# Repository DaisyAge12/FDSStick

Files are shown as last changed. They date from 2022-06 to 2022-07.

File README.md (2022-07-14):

# A new mod approaches!
This is a new method of installing an FDS Stick into a Sharp Twin Famicom
Rather than having to cut the plastic card cover or have an ugly wire hanging around, this mod gives you a nice professional looking install!

#### How to Install

1. Start by printing the modded cover and snap cover

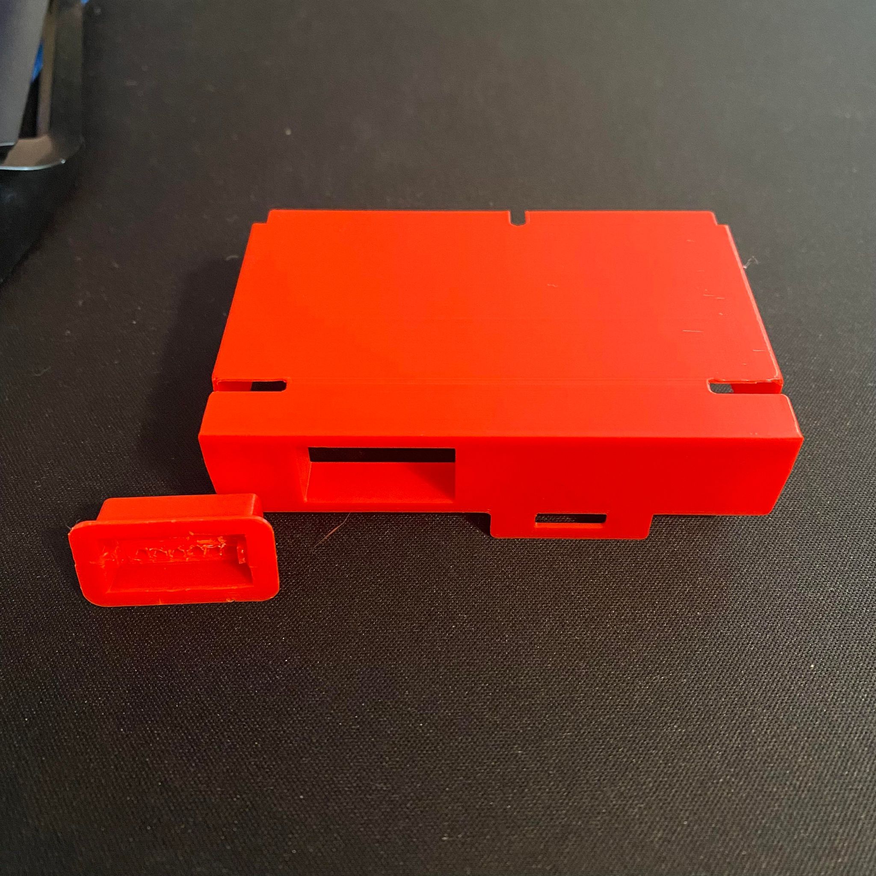
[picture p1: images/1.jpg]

     
2. While that prints (roughly 3 hours) gather materials from the BOM

3. Refer to screenshots for proper installation of the JST connector and header pins

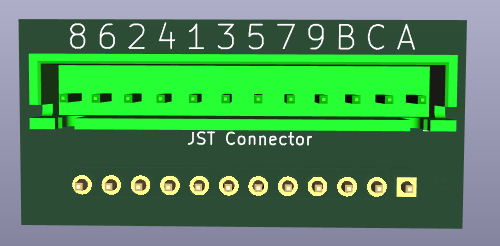
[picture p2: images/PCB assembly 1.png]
 

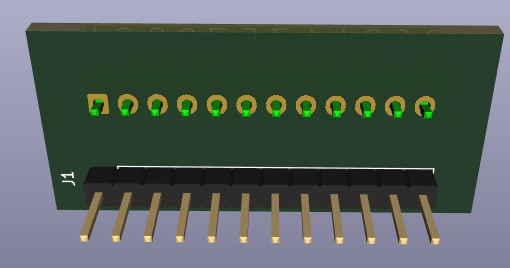
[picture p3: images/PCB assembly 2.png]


4. Use sandpaper, a dremel, or a hot knife to remove the bump from the connector. Note if using a hot knife - pay attention! That's how mine came out so marred.
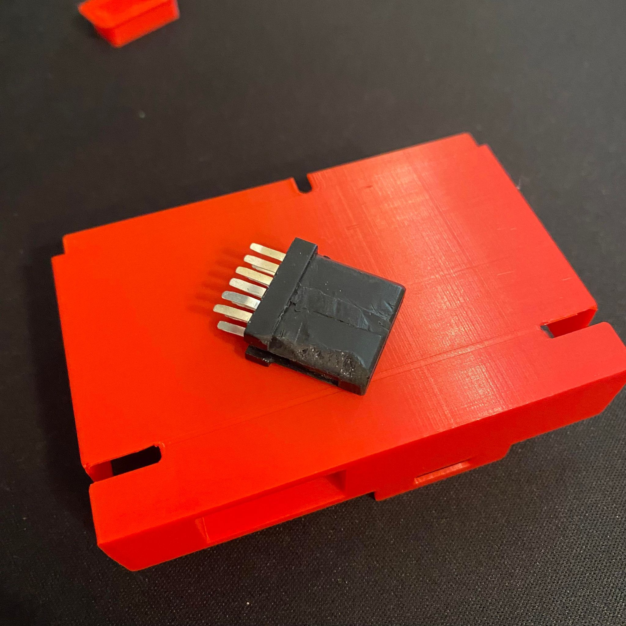
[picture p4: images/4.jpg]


5. Remove locking back for SNES AV and insert the SNES connector into the snap cover (orientation is not important)
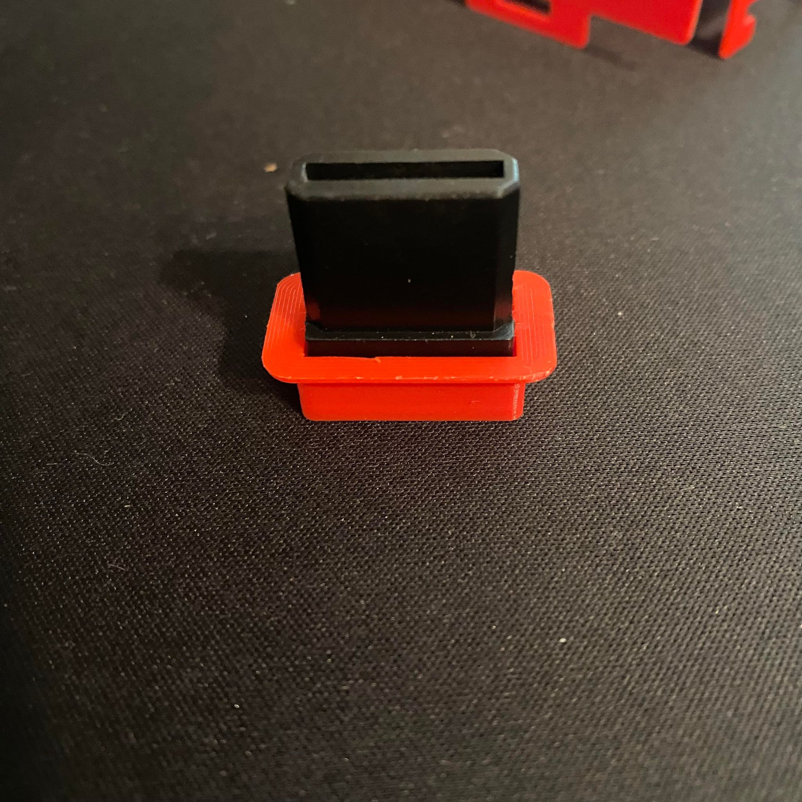
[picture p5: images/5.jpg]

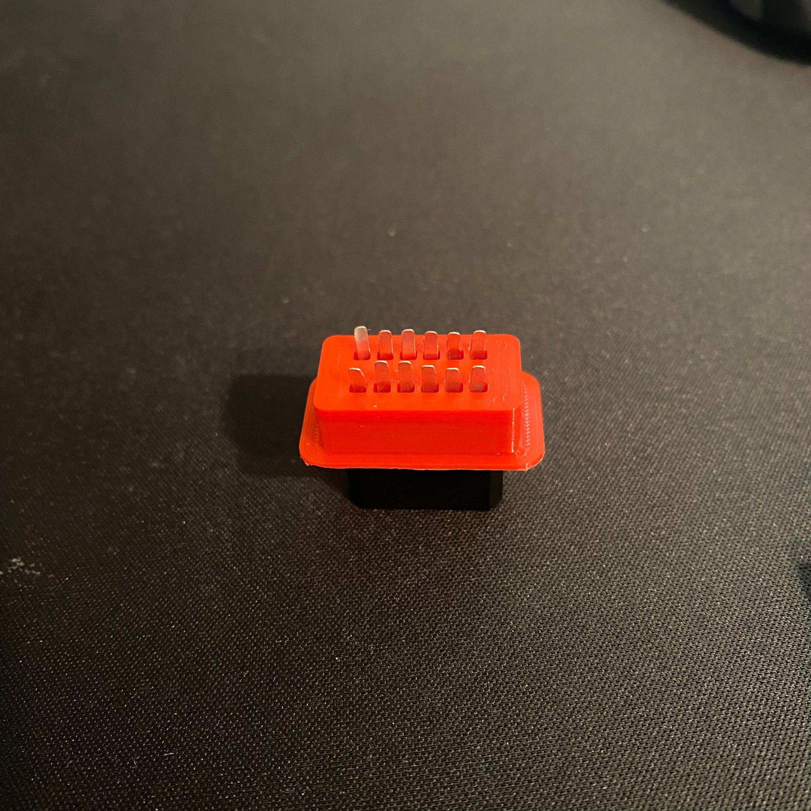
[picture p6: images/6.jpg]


6. Assemble the XHP-12 connector cable as shown in pictures - *do not insert a jumper into pin 12 of the white connector!*
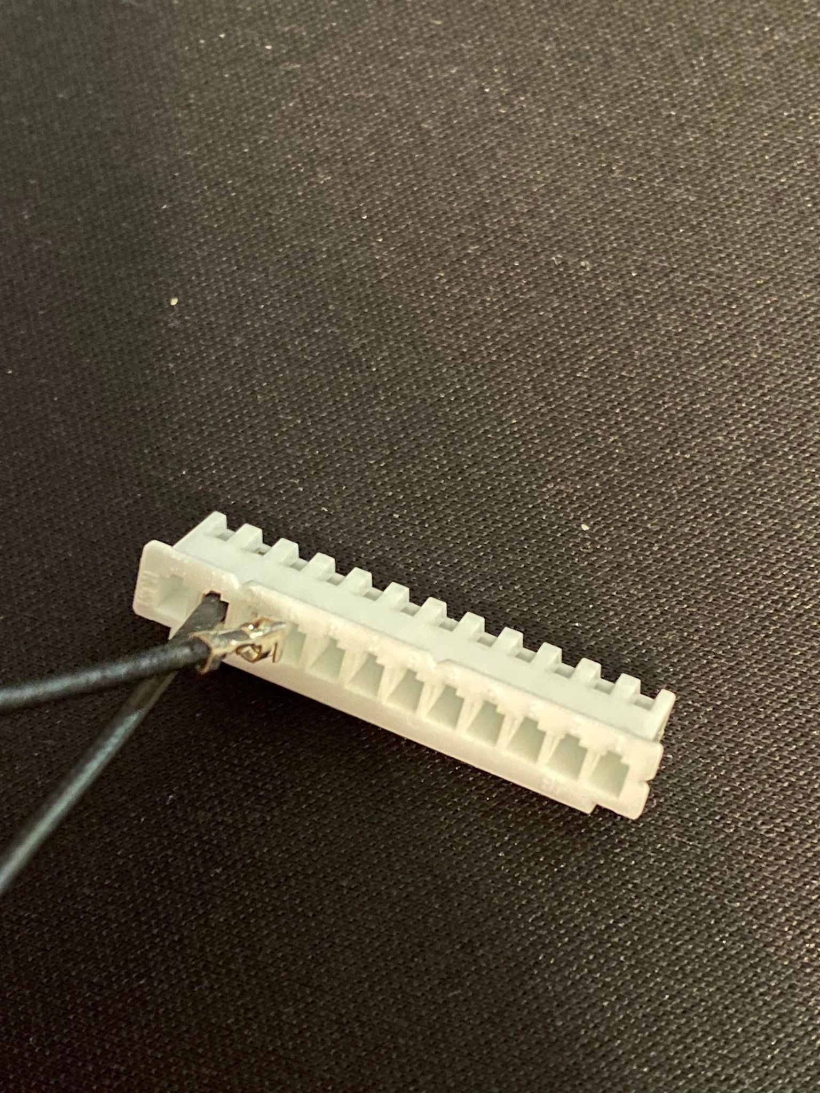
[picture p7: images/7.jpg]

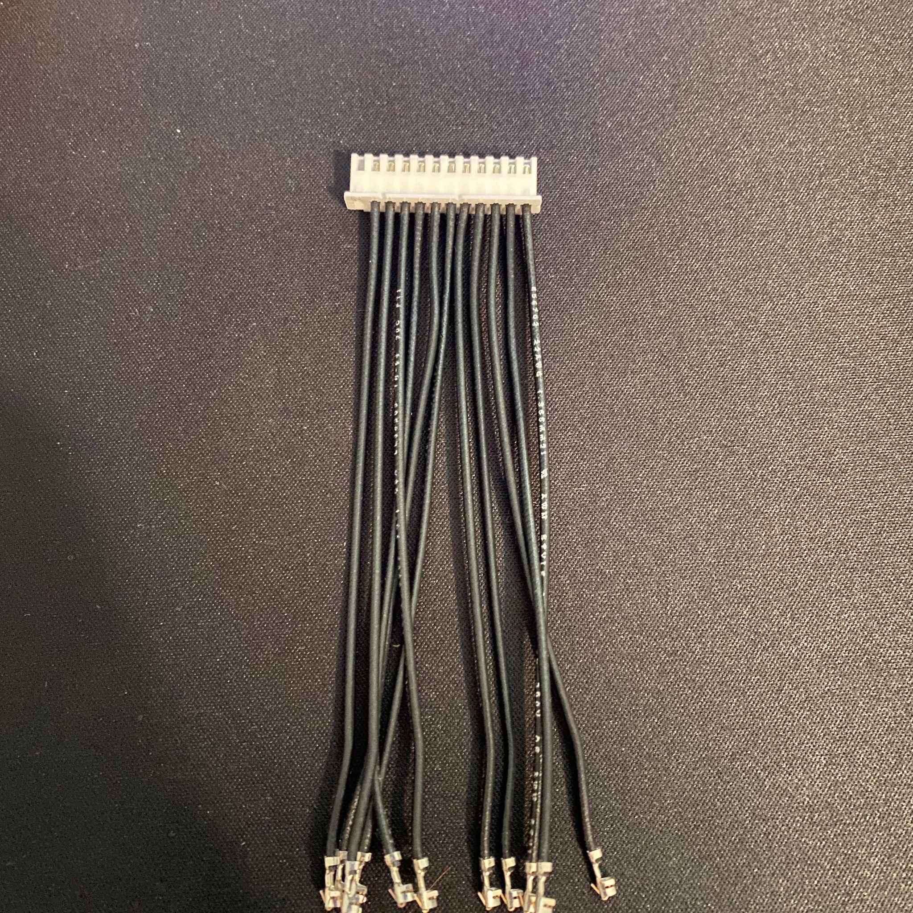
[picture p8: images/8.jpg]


7. Remove the jumper ends and use wire strippers to remove the sheath
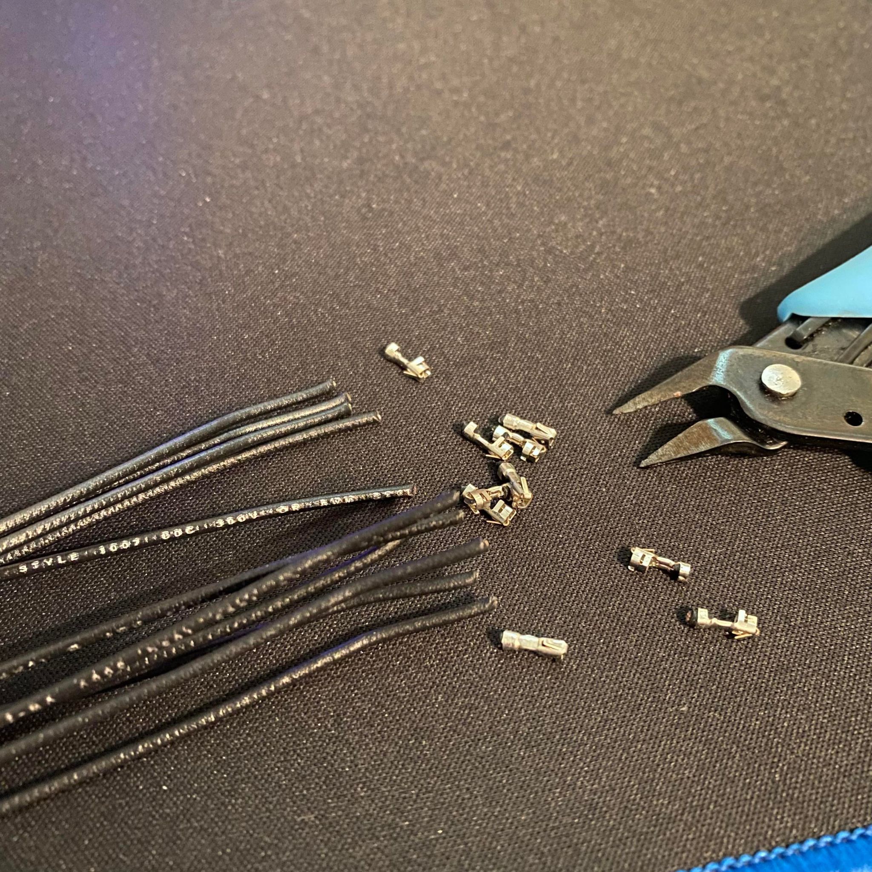
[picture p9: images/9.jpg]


8. Run the wires throught the opening in the modded Twin Famicom cover

9. Install the wires according to this diagram from 3DS Captures site:

**Note**: It is *crucial* that you double check your work as one wrong connection can make your FDS Stick short circuit

**Note**: See how I put my SNES connector upside down? Not only does it hide the ugly parts, it is also my guide so that I know which pins are being soldered to
The goal is to have the FDS Stick facing up so you can easily press the button for flipping disks
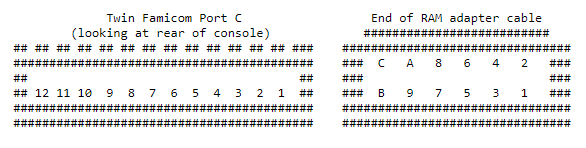
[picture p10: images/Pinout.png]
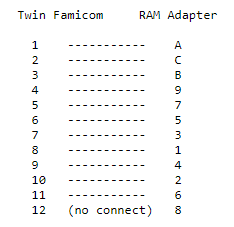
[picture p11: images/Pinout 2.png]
		

10. Insert the ram adapter into the top row of holes in the Twin Famicom - Please see photos 10 & 11
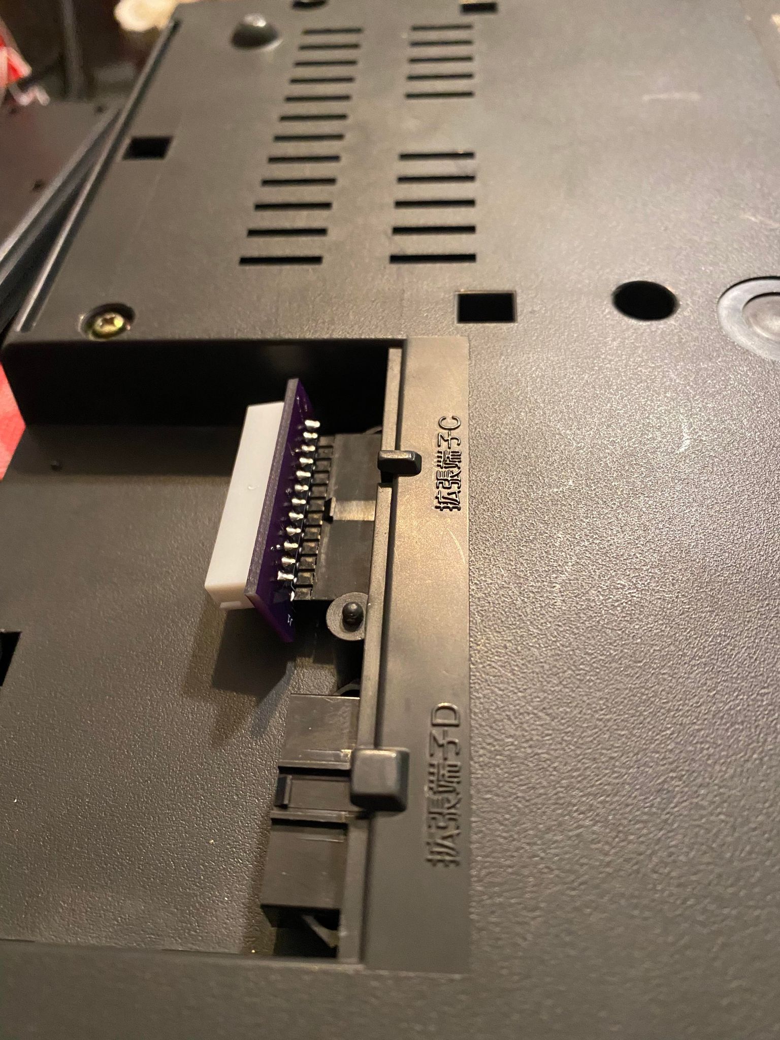
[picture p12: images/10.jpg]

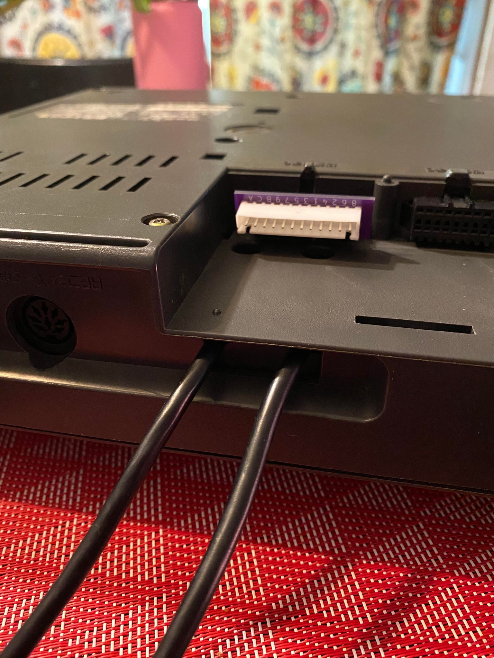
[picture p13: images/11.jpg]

   
11. Carefully snap in the snap cover if you haven't already. If the snap cover isn't tight enough, a small dab of superglue will do the trick.
**Remember** orientation is important! You dont want to fry your FDS Stick
    
12. Connect the white connector
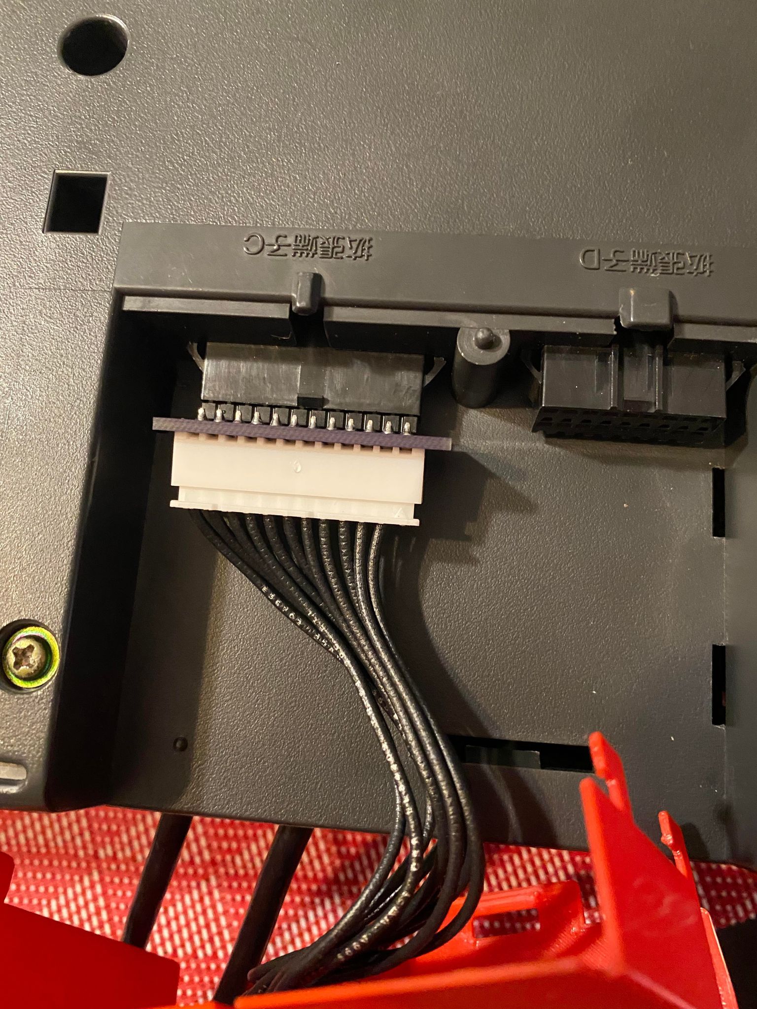
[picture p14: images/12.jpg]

    
13. Carefully install the modded Famicom cover
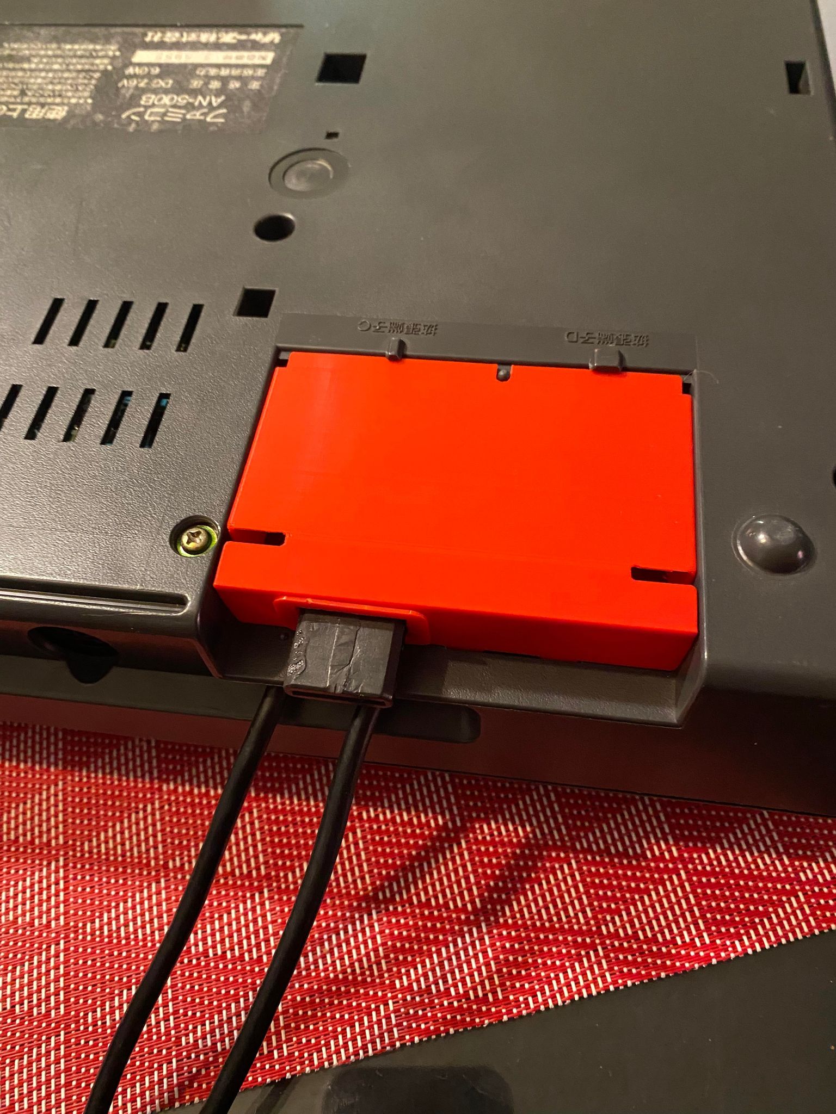
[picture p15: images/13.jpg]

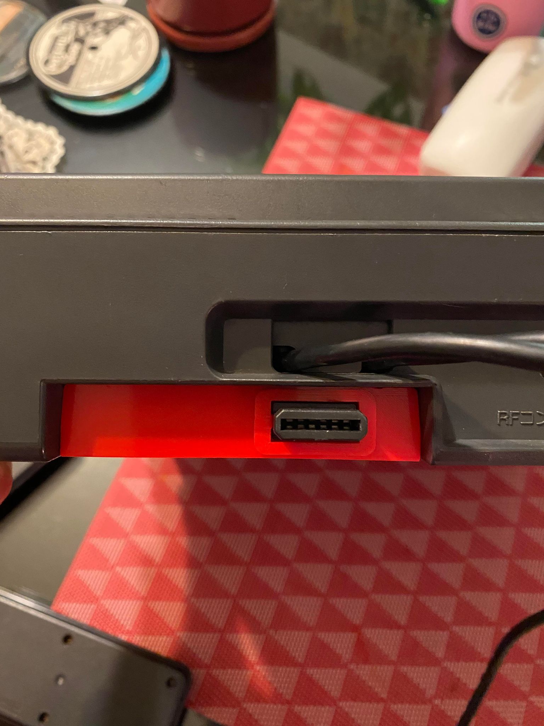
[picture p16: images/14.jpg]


14. Plug in your FDS Stick and enjoy!

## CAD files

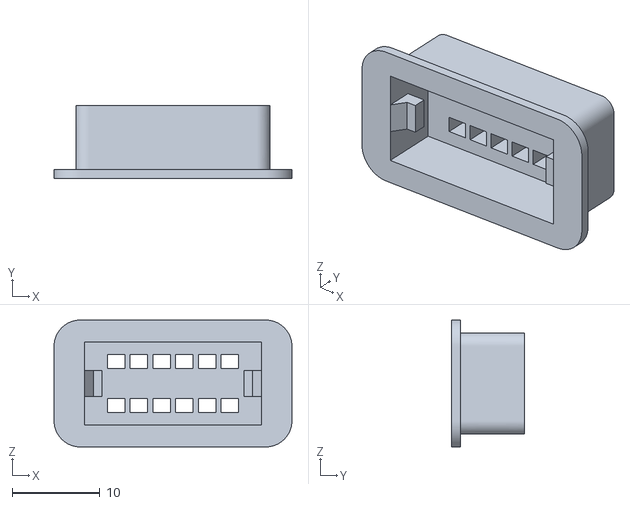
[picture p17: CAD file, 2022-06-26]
3D files/snap cover.stl
27.2 x 8.30 x 14.5

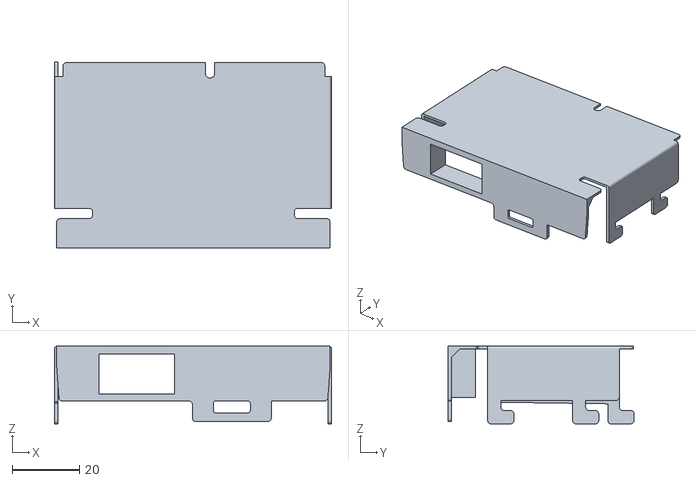
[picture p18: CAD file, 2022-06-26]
3D files/TwinFami modded cover.stl
82.6 x 55.4 x 23.2

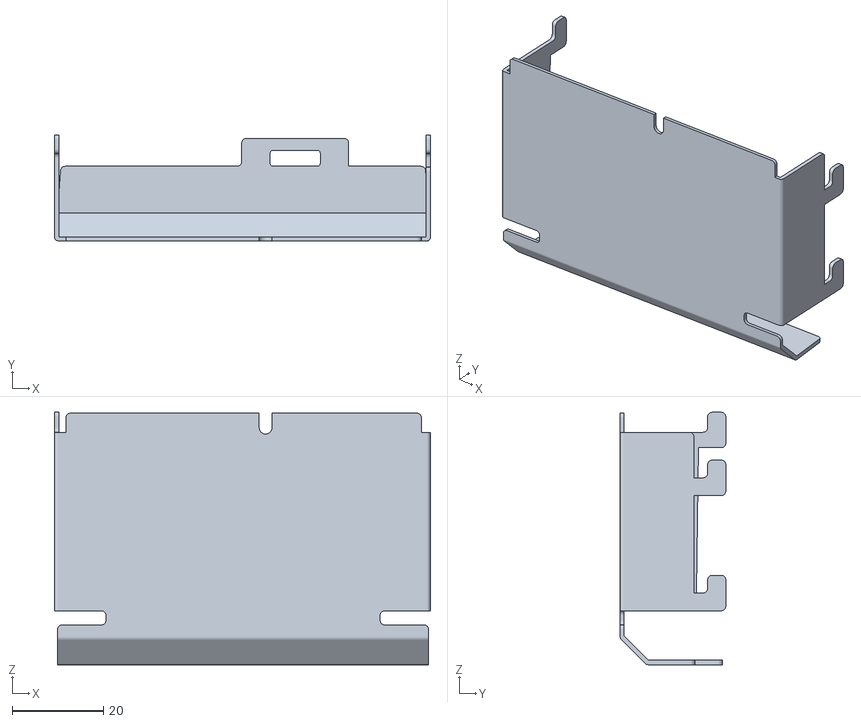
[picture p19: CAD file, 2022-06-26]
3D files/TwinFami Port Cover.stl
82.6 x 23.2 x 55.4

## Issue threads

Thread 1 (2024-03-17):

FDSKey

s3anami, 2024-03-17:
Would this work with the FDSKey as well? Any interest in selling the soldered boards?

DaisyAge12, 2024-03-18:
I don't see why it shouldn't work with FDSKey but I will not be testing it and therefore is technically unsupported. No, I will not be selling soldered boards as there is almost no interest in this mod, I'd be losing money even if I tried to sell at cost. To bypass the board in my mod you could use the cable referenced in the FDSKey github.

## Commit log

2022-06-24 Create BOM
2022-06-24 Bill of Materials for project
2022-06-24 PCB gerbers
2022-06-26 3D files
    Added 3D files to Git.
    For the mod you need FDS and modded cover.
    For replacement cover just use the port cover
    [FDS Snap cover.stl, TwinFami Port Cover.stl, TwinFami modded cover.stl]
2022-06-26 Images
    Connector
2022-06-26 Update BOM
2022-06-26 3D Models
    Updated models
    [FDS Snap cover.stl, TwinFami modded cover.stl]
2022-06-26 Update FDS Snap cover.stl
    Shaved 1mm off the back to leave more exposed pin. Should make it easier to wire up
    [FDS Snap cover.stl]
2022-07-13 moved to 3D files folder
    [FDS Snap cover.stl, TwinFami Port Cover.stl, TwinFami modded cover.stl]
2022-07-14 Rename snap cover.stl
    [snap cover.stl]
